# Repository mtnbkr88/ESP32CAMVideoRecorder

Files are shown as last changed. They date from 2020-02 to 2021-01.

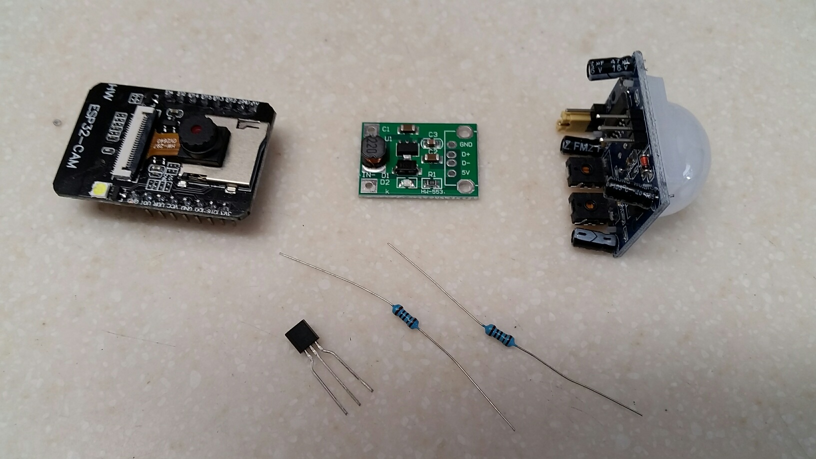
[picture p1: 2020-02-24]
ECVR_Parts.jpg

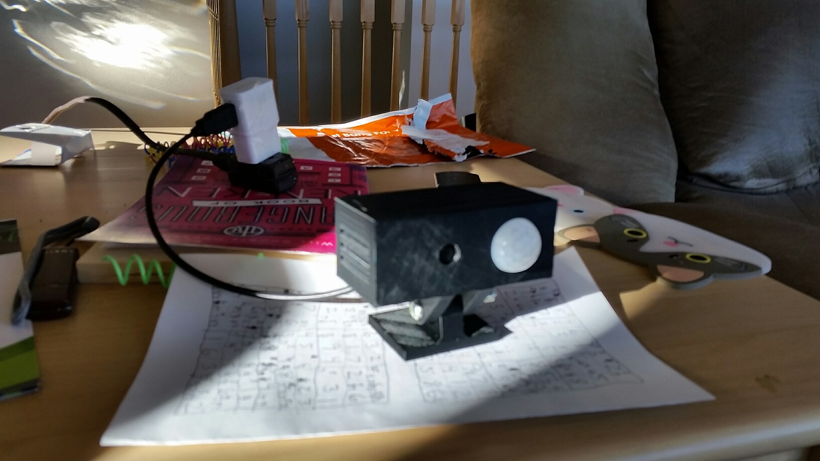
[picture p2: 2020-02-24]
ECVR_Enclosure.jpg

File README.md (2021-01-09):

# ESP32-CAM_Video_Recorder

ESP32-CAM Video Recorder

11/08/2020 Ed Williams 

This version of the ESP32-CAM Video Recorder is built on the work of many other listed in the sketch.
It has been hugely modified to be a fairly complete web camera server with the following capabilities:
  - Record AVI video and peak, stream, download or delete the saved videos.
  - Take JPG pictures and view, download or delete the saved pictures.
  - Up to 100 videos and 100 pictures can be saved on the SD card. Beyond that as more
    are saved the oldest are deleted.
  - Removed the ability to change the size, frame rate and quality. They are permanently 
    set to size 640x480, 100ms and quality 10.
  - Recording times can be set from 10 to 300 seconds
  - Motion detection is available if a PIR motion sensor is connected to GPIO3 (U0RXD)
    (after the firmware is uploaded). 
  - Time action trigger.
  - Remote trigger.
  - Motion detection and time can trigger the following actions:
    - Take a picture.
    - Take a picture and email it.
    - Make a video.
    - Make a video and send an email with name of video.   
  - Motion detection is checked every second and starts checking again one minute
    after a trigger, so if you don't want any gaps in motion detected videos, set 
    recording time to 60 seconds.
  - Normal web traffic is on port 80, streaming comes from port 90. If accessing from 
    outside the local network, forward port X to 80 and port X+10 to port 90.
  - OTA firmware updates on port 90.
  - The original included FTP server was removed since files can now be managed through
    the web site.
  - Note: This sketch uses a simple sendemail library I found on github by Peter Gorasz
    (sendemail.cpp and sendemail.h) but modified by me to allow sending one file from 
    the SD card as an attachment. The sendemail pieces are included in this sketch and 
    can be moved to external files if you want to use them for something else.
  - Use a top quality SD card with at least 16G. If the camera crashes after recording a
    lot of videos, the SD card might be full.

When using the camera and SD card, I was only able to get GPIO3 (U0RXD) pin to work
with the PIR but I had to wire it up as follows:

Use a 2N4401 transistor with the collector hooked to a 1K resistor then hooked to GPIO3
(connect after done uploading sketch). Connect the Dout wire from the PIR to a 1K resistor
then connect to base of transistor. Connect the emitter of the transistor to GND. See
ECVR_Schematic.jpg for a picture of the wiring.

Used pinMode(GPIO_NUM_3, INPUT_PULLUP) in the setup to pull the pin high. Now when 
motion is detected, GPIO3 will be pulled low, otherwise it will be high.

ECVR_Main_Screen.png shows the main screen for the ESP32-CAM Video Recorder web site.

ECVR_Parts.jpg shows the parts used.

The files ECVR_Box.stl, ECVR_Box_Cover.stl and ECVR_Box_Base.stl are stl files for
3D printing an enclosure to hold everything.

ECVR_Enclosure.jpg show the completed project.

If a motion detect or time trigger video is being recorded and send an email is enabled,
the email sometimes does not get sent. The socket for connecting to the email server fails.
I haven't figured this one out yet.

The Default Partition Scheme must be used for compiling so OTA can work.

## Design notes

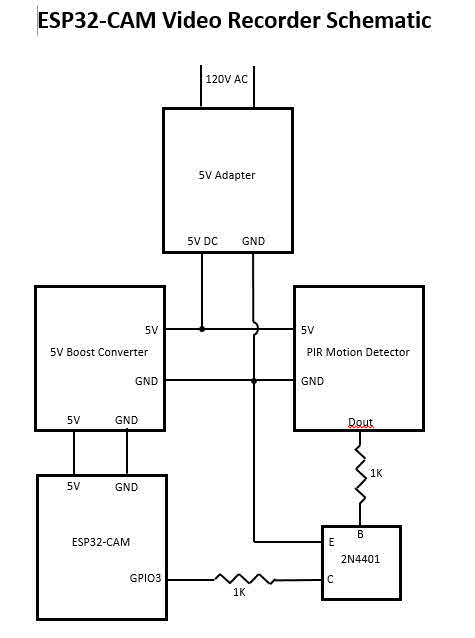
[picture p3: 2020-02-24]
ECVR_Schematic.jpg

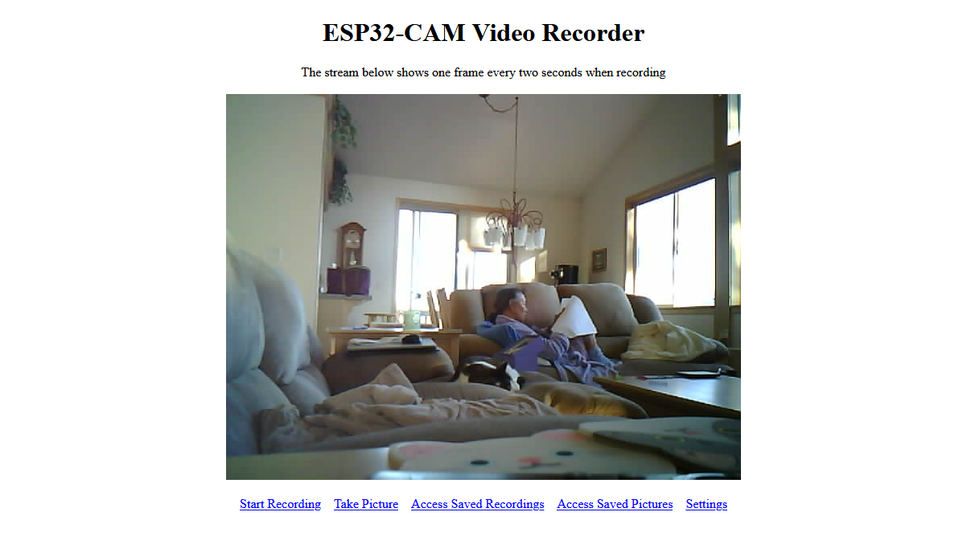
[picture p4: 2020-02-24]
ECVR_Main_Screen.png

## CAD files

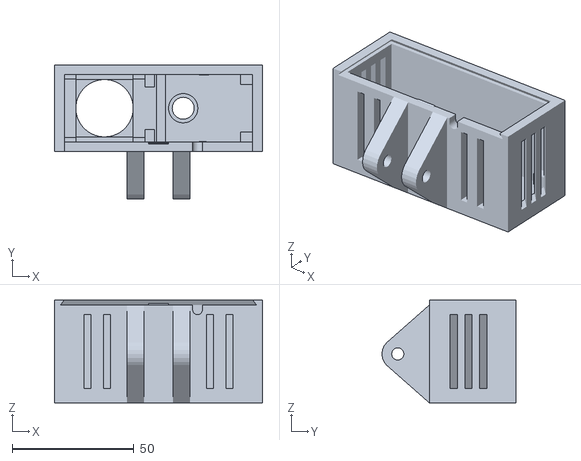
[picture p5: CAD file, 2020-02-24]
ECVR_Box.stl
85.2 x 55.0 x 42.2

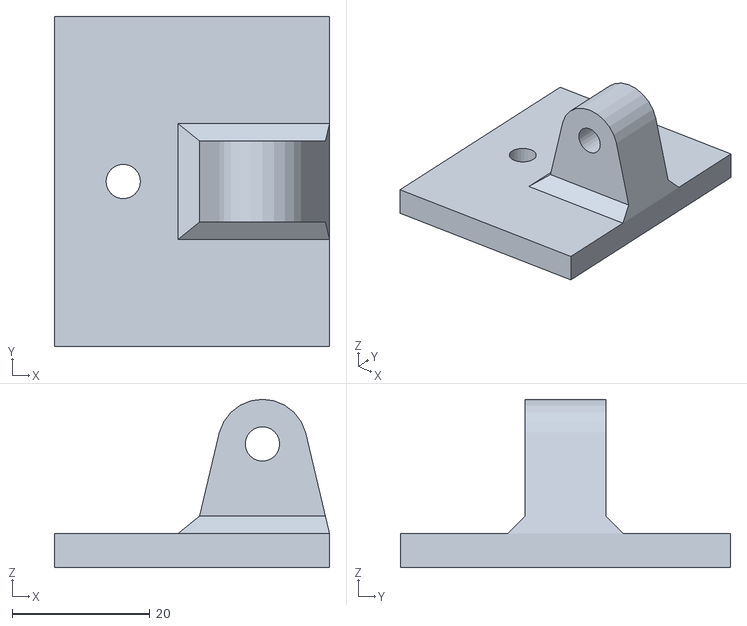
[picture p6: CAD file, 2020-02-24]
ECVR_Box_Base.stl
40.0 x 48.0 x 24.5

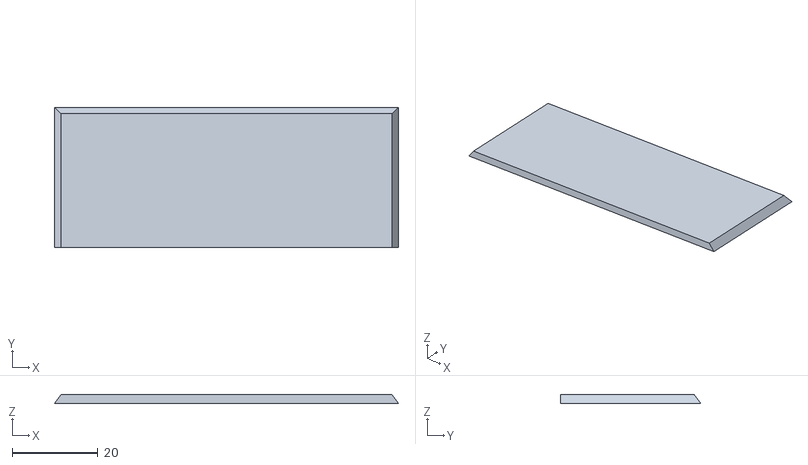
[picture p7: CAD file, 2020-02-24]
ECVR_Box_Cover.stl
80.2 x 32.8 x 2.00

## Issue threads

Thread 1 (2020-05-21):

Adding motion detection without PIR

thomas-pegot, 2020-05-21:
Hi,

>   - Motion detection is available if a PIR motion sensor is connected to GPIO3 (U0RXD)
>     (after the firmware is uploaded).

I you are interested in motion detection from video, I developped an algo based on optical flow which can be used to detect motion detection for esp32cam.

Link : https://github.com/thomas-pegot/esp32-motion

best,

mtnbkr88, 2020-05-21:
Hi,

Yes, I am interested in motion detection without using PIR. I thought about trying this myself many months ago but haven't gotten around to it yet. The PIR I'm using gives tons of false positives on hot or windy days (my cameras are outside). Detecting motion from video could solve the false positives from heat but I think there's nothing that can be done for windy days (lots of tree movement). When I get the chance I'll take a look at what you've done.

Thanks!

________________________________
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

thomas-pegot, 2020-05-30:
Ok take your time.
I added a repo presenting the motion library : https://github.com/thomas-pegot/camera_web_server
peace

Closed 2020-11-14.

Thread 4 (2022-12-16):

pir motion detection

yousefhstm, 2022-12-16:
hi mtnbkr88
1-great thank for you and your code skill
2-i upload the code and wire the circuit just like u say but madule donot take action ...even i measure the gpio 3 (it vas 0.6 volt )...how can i fix it? is it possible to change gpio 3 to low (input pulldown) and trigge it with pir(dout)?
3- some time my ESP32-CAM hangs(stick in reboot process) and the red led gose on continually (even after power off - on) until i program it with  standard EXAMPLE " CameraWebServer "that contain (define CAMERA_MODEL_AI_THINKER) then i can upload your code and get woke again ... it seem has issu with "ESP32 Wrover Module". how dose it fix?
thanks

mtnbkr88, 2022-12-16:
Hi yousefhstm,
1 - Thank you
2 - I use GPIO 13 and this code to initialize it: pinMode(GPIO_NUM_13, INPUT_PULLDOWN); so it gets triggered when PIT (DOUT) goes high.
3 - The red light is supposed to stay on during the setup phase and turn off once it goes into the loop phase. It is strange that it hangs in the setup phase for you. I use Arduino 1.8.15 and "ESP32 Wrover Module" as the board and in the code I used the pin definitions for CAMERA_MODEL_AI_THINKER. Have you tried connecting your module to your PC and using the Serial Monitor to hopefully see where it is hanging? You might have to add Serial.println statements in various places to hopefully catch where it is getting stuck. That's what I do for these situations.

Closed 2022-12-16.

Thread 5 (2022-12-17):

time trigger

yousefhstm, 2022-12-17:
hello dear mtnbkr88
 1_thanks for prev giude .it was help full and pir get work
2_ i wanna to take video or photo every 2min (for example) so i set "time trigger"at H=0 & M=2 but madule didnt take action...what can ido?
3_how can i turn the "SMD FLASH LAMP" off during madule work time?

mtnbkr88, 2022-12-18:
Hi Yousefhstm,
1 - Glad you got it working.
2 - Time Trigger is used to wake up the ESP32 at a specific time once a day for 10 minutes. This allows a person to remotely connect to the ESP32 to change settings or update firmware. My ESP32 is sitting on a fence in the yard with a solar panel attached. Using the time trigger mine wakes up once a day at 13:00 so I can make changes to settings without going outside.
3 - The SMD FLASH LAMP is connected to pin 4. You can try the following in your setup function to turn off the LED:
  pinMode(4, OUTPUT);     // flash led on chip
  digitalWrite(4, LOW);   // turn off the flash LED on chip
However pin 4 is also one of the pins used to access the SD card so the white LED will flash when the SD card is accessed. There's nothing that can be done about that. If you find a schematic of the ESP32CAM you will find this to be so. If the flash is really bothering you put a piece of black electrical tape over it.

yousefhstm, 2022-12-18:
Thanks

yousefhstm, 2022-12-18:
if this code have ota , how can i use it?

mtnbkr88, 2022-12-18:
Yes, this code has OTA. Here's how to use it:
1 - In the Arduino IDE choose Sketch->Export compiled binary. This will create the .bin file to upload.
2 - With the ESP32 being awake, go to http://<your_ip>/updatefirmware.
3 - Browse to and choose the .bin file saved above, enter the Update Password (the default is 12345678 if you did not change it) then choose Update.

yousefhstm, 2022-12-18:
Thank you

Closed 2022-12-18.

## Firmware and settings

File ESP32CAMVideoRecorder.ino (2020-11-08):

/********************************************************************************************

ESP32-CAM Video Recorder

11/08/2020 Ed Williams 

This version of the ESP32-CAM Video Recorder is built on the work of many other listed below.
It has been hugely modified to be a fairly complete web camera server with the following
capabilities:
  - Record AVI video and peak, stream, download or delete the saved videos.
  - Take JPG pictures and view, download or delete the saved pictures.
  - Save up to 100 videos and 100 pictures on the SD card. Beyond that as more are saved 
    the oldest are deleted.
  - Removed the ability to change the size, frame rate and quality. They are permanently 
    set to size 640x480, 100ms and quality 10.
  - Recording times can be set from 10 to 300 seconds
  - Motion detection is available if a PIR motion sensor is connected to GPIO3 (U0RXD)
    (after the firmware is uploaded). 
  - Time action trigger.
  - Remote trigger.
  - Motion detection and time can trigger the following actions:
    - Take a picture.
    - Take a picture and email it.
    - Make a video.
    - Make a video and send an email with name of video.
  - Motion detection is checked every second and starts checking again one minute
    after a trigger, so if you don't want any gaps in motion detected videos, set 
    recording time to 60 seconds.
  - Normal web traffic is on port 80, streaming comes from port 90. If accessing from 
    outside local network, forward port X to 80 and port X+10 to port 90.
  - OTA firmware updates on port 90.
  - The originally included FTP server was removed since files can now be managed through
    the web site.
  - Note: This sketch uses a simple sendemail library I found on github by Peter Gorasz
    (sendemail.cpp and sendemail.h) but modified by me to allow sending one file from 
    the SD card as an attachment. The sendemail pieces are included in this sketch and 
    can be moved to external files if you want to use them for something else.
  - Use a top quality SD card with at least 16G. If the camera crashes after recording a
    lot of videos, look on the Settings screeen to see if the SD card is full.

When using the camera and SD card, I was only able to get GPIO3 (U0RXD) pin to work
with the PIR but I had to wire it up as follows:

Use a 2N4401 transistor with the collector hooked to a 1K resistor then hooked to GPIO3
(connect after done uploading sketch). Connect the Dout wire from the PIR to a 1K resistor
then connect to base of transistor. Connect the emitter of the transistor to GND.

Used pinMode(GPIO_NUM_3, INPUT_PULLUP) in the setup to pull the pin high. Now when 
motion is detected, GPIO3 will be pulled low, otherwise it will be high.

For the remote trigger, connect to this server with a url like:
<this_server>/remotetrigger?action=10  (use 10 through 13 for the desired action)
  10 - Take a picture, 11 - Take a picture and email it, 12 - Take a video,
  13 - Take a video and email the video name

If a motion detect or time trigger video is being recorded and send an email is enabled,
the email sometimes does not get sent. The socket for connecting to the email server fails.
I haven't figured this one out yet.

The Default Partition Scheme must be used for compiling so OTA can work.


The descriptons below are from authors of previous versions of this sketch and some of 
the capabilities they describe, like using an FTP Server and changing size, frame rate 
and quality of recorded videos have been removed.

****************************************************************************************/

/* start of others old comments ********************************************************
***********************************************************************************************************************************************************
 *  TITLE: This sketch is derived from the following Github repository and is mainly for testing the current work done by the team. It allows you 
 *  to record video onto a microSD card, using the ESP32-CAM board. Videos can be remotely obtained by accessing the FTP server contained within the sketch.
 *
 *  By Frenoy Osburn
 *  YouTube Video: https://youtu.be/lc_gXfkoRZo
 *  BnBe Post: https://www.bitsnblobs.com/video-recording-with-the-esp32-cam-board
 ***********************************************************************************************************************************************************/
/********************************************************************************************************************
 *  Board Settings:
 *  Board: "ESP32 Wrover Module"
 *  Upload Speed: "921600"
 *  Flash Frequency: "80MHz"
 *  Flash Mode: "QIO"
 *  Partition Scheme: "Hue APP (3MB No OTA/1MB SPIFFS)"
 *  Core Debug Level: "None"
 *  COM Port: Depends *On Your System*
 *********************************************************************************************************************/
 
 /*
  TimeLapseAvi

  ESP32-CAM Video Recorder

  This program records an AVI video on the SD Card of an ESP32-CAM.

  by James Zahary July 20, 2019  TimeLapseAvi23x.ino
     jamzah.plc@gmail.com

  https://github.com/jameszah/ESP32-CAM-Video-Recorder
    jameszah/ESP32-CAM-Video-Recorder is licensed under the
    GNU General Public License v3.0

  ~~~
  Update Sep 15, 2019 TimeLapseAvi39x.ino
  - work-in-progress
  - I'm publishing this as a few people have been asking or working on this
  
  - program now uses both cpu's with cpu 0 taking pictures and queue'ing them
    and a separate task on cpu 1 moving the pictures from the queue and adding
    them to the avi file on the sd card
  - the loop() task on cpu 1 now just handles the ftp system and http server
  - dropped fixed ip and switch to mDNS with name "desklens", which can be typed into
    browser, and also used as wifi name on router
  - small change to ftp to cooperate with WinSCP program
  - fixed bug so Windows would calulcate the correct length (time length) of avi 
  - when queue of frames gets full, it slips every other frame to try to catch up
  - camera is re-configued when changing from UXGA <> VGA to allow for more buffers 
    with the smaller frames
  ~~~

  The is Arduino code, with standard setup for ESP32-CAM
    - Board ESP32 Wrover Module
    - Partition Scheme Huge APP (3MB No OTA)

  This program records an AVI video on the SD Card of an ESP32-CAM.

  It will record realtime video at limited framerates, or timelapses with the full resolution of the ESP32-CAM.
  It is controlled by a web page it serves to stop and start recordings with many parameters, and look through the viewfinder.

  You can control framesize (UXGA, VGA, ...), quality, length, and fps to record, and fps to playback later, etc.

  There is also an ftp server to download the recordings to a PC.

  Instructions:

  The program uses a fixed IP of 192.168.1.188, so you can browse to it from your phone or computer.

  http://192.168.1.188/ -- this gives you the status of the recording in progress and lets you look through the viewfinder

  http://192.168.1.188/stop -- this stops the recording in progress and displays some sample commands to start new recordings

  ftp://192.168.1.188/ -- gives you the ftp server

  The ftp for esp32 seems to not be a full ftp.  The Chrome Browser and the Windows command line ftp's did not work with this, but
  the Raspbarian command line ftp works fine, and an old Windows ftp I have called CoffeeCup Free FTP also works, which is what I have been using.
  You can download at about 450 KB/s -- which is better than having to retreive the SD chip if you camera is up in a tree!

  http://192.168.1.188/start?framesize=VGA&length=1800&interval=250&quality=10&repeat=100&speed=1&gray=0  -- this is a sample to start a new recording

  framesize can be UXGA, SVGA, VGA, CIF (default VGA)
  length is length in seconds of the recording 0..3600 (default 1800)
  interval is the milli-seconds between frames (default 200)
  quality is a number 5..50 for the jpeg  - smaller number is higher quality with bigger and more detailed jpeg (default 10)
  repeat is a number of how many of the same recordings should be made (default 100)
  speed is a factor to speed up realtime for a timelapse recording - 1 is realtime (default 1)
  gray is 1 for a grayscale video (default 0 - color)

  These factors have to be within the limit of the SD chip to receive the data.
  For example, using a LEXAR 300x 32GB microSDHC UHS-I, the following works for me:

  UXGA quality 10,  2 fps (or interval of 500ms)
  SVGA quality 10,  5 fps (200ms)
  VGA  quality 10, 10 fps (100ms)
  CIG  quality 10, 20 fps (50ms)

  If you increase fps, you might have to reduce quality or framesize to keep it from dropping frames as it writes all the data to the SD chip.

  Also, other SD chips will be faster or slower.  I was using a SanDisk 16GB microSDHC "Up to 653X" - which was slower and more unpredictable than the LEXAR ???

  Search for "zzz" to find places to modify the code for:
    1.  Your wifi name and password
    2.  Your preferred ip address (with default gateway, etc)
    3.  Your Timezone for use in filenames
    4.  Defaults for framesize, quality, ... and if the recording should start on reboot of the ESP32 without receiving a command

  Acknowlegements:

  1.  https://robotzero.one/time-lapse-esp32-cameras/
      Timelapse programs for ESP32-CAM version that sends snapshots of screen.
  2.  https://github.com/nailbuster/esp8266FTPServer
      ftp server (slightly modifed to get the directory function working)
  3.  https://github.com/ArduCAM/Arduino/tree/master/ArduCAM/examples/mini
      ArduCAM Mini demo (C)2017 LeeWeb: http://www.ArduCAM.com
      I copied the structure of the avi file, some calculations.

end of others old comments ***************************************************************
******************************************************************************************/


// edit the below for local settings 

// wifi info
const char* ssid = "YourSSID";
const char* password = "YourSSIDPwd";
// fixed IP info
const uint8_t IP_Address[4] = {192, 168, 2, 30};
const uint8_t IP_Gateway[4] = {192, 168, 2, 1};
const uint8_t IP_Subnet[4] = {255, 255, 255, 0};
const uint8_t IP_PrimaryDNS[4] = {8, 8, 8, 8};
const uint8_t IP_SecondaryDNS[4] = {8, 8, 4, 4};

const char* TZ_INFO = "PST8PDT,M3.2.0/2:00:00,M11.1.0/2:00:00";

const int SERVER_PORT = 80;  // port the the web server is listening on
            // the stream web server will be listening on this port + 10 

// edit email server info for the send part, recipient address is set through Settings in the app
const char* emailhost = "smtp.gmail.com";
const int emailport = 465;
const char* emailsendaddr = "YourEmail\@gmail.com";
const char* emailsendpwd = "YourEmailPwd";
char email[40] = "DefaultMotionDetectEmail\@hotmail.com";  // this can be changed through Settings in the app

// OTA update stuff
const char* appName = "ESP32CamVideoRecorder";
const char* appVersion = "1.4.3";
const char* firmwareUpdatePassword = "87654321";

// should not need to edit the below

#include <Update.h>  // for flashing new firmware

//#define LOG_LOCAL_LEVEL ESP_LOG_VERBOSE
#include "esp_log.h"
#include "esp_http_server.h"
#include "esp_camera.h"

//#include <WiFi.h>   // redundant

//#include "SD_MMC.h"  // redundant
//#include <FS.h>      // redundant


/**********************************************************************************
 * 
 *  From here to end comment below is the contents of sendemail.h
 *
 *  If an SD card is used, it is assumed to be mounted on /sdcard.
 * 
 */

#ifndef __SENDEMAIL_H
#define __SENDEMAIL_H

// uncomment for debug output on Serial port
//#define DEBUG_EMAIL_PORT

// uncomment if using SD card
#define USING_SD_CARD

#include <WiFiClient.h>
#include <WiFiClientSecure.h>
#include <base64.h>

#ifdef USING_SD_CARD
#include <FS.h>
#include "SD_MMC.h"
#endif


class SendEmail
{
  private:
    const String host;
    const int port;
    const String user;
    const String passwd;
    const int timeout;
    const bool ssl;
    WiFiClient* client;
    String readClient();

    // stuff for attaching buffers (could be images and videos held in memory)
    int attachbuffercount;  // current number of buffer attachments
    static const int attachbuffermaxcount = 10;  // max number of buffers that can be attached
    struct attachbufferitem {
      char * buffername;  // name for buffer
      char * buffer;  // pointer to buffer
      size_t buffersize;  // number of bytes in buffer
    };
    attachbufferitem attachbufferitems[attachbuffermaxcount];
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
void loop()
{
/*
  if (WiFi.status() != WL_CONNECTED) {
    init_wifi();
    Serial.println("***** WiFi reconnect *****");
  }
*/
  if (millis() - last_wakeup_1sec > (1000) ) {       // 1 second
    last_wakeup_1sec = millis();

    if (WiFi.status() != WL_CONNECTED) {
      init_wifi();
      Serial.println("***** WiFi reconnect *****");
    }

    if ( motionDetect > 9 && motion == 0 && !digitalRead( PIR_Pin ) ) { // Low if motion detected
      int mcount = 0;
      while ( !digitalRead ( PIR_Pin ) && mcount < 4 ) {
        delay(5);
        mcount++;
        if ( mcount == 4 ) {
          // function to handle motion detected
          motion = 1;
          motion1min = millis();
          process_Detection(0);  // 0 is motion detection 
        }
      }
      
    }
  }

  if ( millis() - last_wakeup_1min > (1 * 60 * 1000) ) {       // 1 minute
    last_wakeup_1min = millis();

    // check current time and restart web servers after midnight (in case it got stuck during the day)
    struct tm timeinfo;
    if (!getLocalTime(&timeinfo)) {
      Serial.println("Failed to obtain time");
    } else {
      char hc[3];  // current hour
      strftime(hc, sizeof(hc), "%H", &timeinfo);
      int h = atoi(hc);
      char mc[3];  // current minute
      strftime(mc, sizeof(mc), "%M", &timeinfo);
      int m = atoi(mc);

      // restart stream web server at midnight just in case it is stuck
      if ( h == 0 && m == 0 ) {
        Serial.println("Daily restart of StreamServer");
        stopStreamServer();
        delay(500);
        startStreamServer();
      }

      // check if time trigger happened
      if ( triggerDetect > 9 && triggerH == h && triggerM == m ) {
        // do time trigger
        process_Detection(1);  // 1 is time trigger detection 
      }
    }
  }

  if ( millis() - motion1min > (1 * 60 * 1000) && motion == 1 ) {  // 1 motion minute
    // allow motion detection after 1 minute
    motion = 0;
  }
 
  if (millis() - last_wakeup_10min > (10 * 60 * 1000) ) {       // 10 minutes
    last_wakeup_10min = millis();
    print_stats("Wakeup in loop() Core: ");
/*
    // restart the main camera web server - it easily gets stuck
    Serial.println("Restarting CameraServer in case it got stuck");
    stopCameraServer();
    delay(500);
    startCameraServer();
*/    
  }

  delay(200);

}


/*****************************************************************************
 * 
 *  From here to the end is the contents of sendemail.cpp
 *  This version can send text or binary objects (jpg, avi) from memory as attachments
 *  and can send files from the SD card mounted on /sdcard.
 *  
 *  *** Uncomment the #include if the below is moved back into sendemail.cpp ***
 *
 */

//#include "sendemail.h"

SendEmail::SendEmail(const String& host, const int port, const String& user, const String& passwd, const int timeout, const bool ssl) :
    host(host), port(port), user(user), passwd(passwd), timeout(timeout), ssl(ssl), client((ssl) ? new WiFiClientSecure() : new WiFiClient())
{
  attachbuffercount = 0;
#ifdef USING_SD_CARD
  attachfilecount = 0;
#endif
}

String SendEmail::readClient()
{
  String r = client->readStringUntil('\n');
  r.trim();
  while (client->available()) r += client->readString();
  return r;
}

void SendEmail::attachbuffer(char * name, char * bufptr, size_t bufsize)
{
  attachbufferitems[attachbuffercount].buffername = (char *) malloc( strlen(name)+1 );
  strcpy( attachbufferitems[attachbuffercount].buffername, name ); 
  attachbufferitems[attachbuffercount].buffer = bufptr;
  attachbufferitems[attachbuffercount].buffersize = bufsize;
  
  attachbuffercount++;
}

#ifdef USING_SD_CARD
void SendEmail::attachfile(char * name)
{
  attachfileitems[attachfilecount].filename = (char *) malloc( strlen(name)+8 );
  strcpy( attachfileitems[attachfilecount].filename, "/sdcard" );
  strcat( attachfileitems[attachfilecount].filename, name );
  
  attachfilecount++;
}
#endif


bool SendEmail::send(const String& from, const String& to, const String& subject, const String& msg)
{
  if (!host.length())
  {
    return false;
  }
  String buffer2((char *)0);  // create String without memory allocation
  buffer2.reserve(800);  // now allocate bytes for string, really should only use 780 of it
  client->stop();
  client->setTimeout(timeout);
  // smtp connect
#ifdef DEBUG_EMAIL_PORT
  Serial.print(F("Connecting: "));
  Serial.print(host);
  Serial.print(":");
  Serial.println(port);
#endif
  if (!client->connect(host.c_str(), port))
  {
    return false;
  }
  String buffer = readClient();
#ifdef DEBUG_EMAIL_PORT
  Serial.print(F("SERVER->CLIENT: "));
  Serial.println(buffer);
#endif
  // note: F(..) as used below puts the string in flash instead of RAM
  if (!buffer.startsWith(F("220")))
  {
    return false;
  }
  buffer = F("HELO ");
  buffer += client->localIP();
  client->println(buffer);
#ifdef DEBUG_EMAIL_PORT
  Serial.print(F("CLIENT->SERVER: "));
  Serial.println(buffer);
#endif
  buffer = readClient();
#ifdef DEBUG_EMAIL_PORT
  Serial.print(F("SERVER->CLIENT: "));
  Serial.println(buffer);
#endif
  if (!buffer.startsWith(F("250")))
  {
    return false;
  }
  if (user.length()>0  && passwd.length()>0 )
  {
    buffer = F("AUTH LOGIN");
    client->println(buffer);
#ifdef DEBUG_EMAIL_PORT
  Serial.print(F("CLIENT->SERVER: "));
  Serial.println(buffer);
#endif
    buffer = readClient();
#ifdef DEBUG_EMAIL_PORT
  Serial.print(F("SERVER->CLIENT: "));
  Serial.println(buffer);
#endif
    if (!buffer.startsWith(F("334")))
    {
      return false;
    }
    base64 b;
    buffer = user;
    buffer = b.encode(buffer);
    client->println(buffer);
#ifdef DEBUG_EMAIL_PORT
  Serial.print(F("CLIENT->SERVER: "));
  Serial.println(buffer);
#endif
    buffer = readClient();
#ifdef DEBUG_EMAIL_PORT
  Serial.print(F("SERVER->CLIENT: "));
  Serial.println(buffer);
#endif
    if (!buffer.startsWith(F("334")))
    {
      return false;
    }
    buffer = this->passwd;
    buffer = b.encode(buffer);
    client->println(buffer);
#ifdef DEBUG_EMAIL_PORT
  Serial.print(F("CLIENT->SERVER: "));
  Serial.println(buffer);
#endif
    buffer = readClient();
#ifdef DEBUG_EMAIL_PORT
  Serial.print(F("SERVER->CLIENT: "));
  Serial.println(buffer);
#endif
    if (!buffer.startsWith(F("235")))
    {
      return false;
    }
  }
  // smtp send mail
  buffer = F("MAIL FROM: ");
  buffer += from;
  client->println(buffer);
#ifdef DEBUG_EMAIL_PORT
  Serial.print(F("CLIENT->SERVER: "));
  Serial.println(buffer);
#endif
  buffer = readClient();
#ifdef DEBUG_EMAIL_PORT
  Serial.print(F("SERVER->CLIENT: "));
  Serial.println(buffer);
#endif
  if (!buffer.startsWith(F("250")))
  {
    return false;
  }
  buffer = F("RCPT TO: ");
  buffer += to;
  client->println(buffer);
#ifdef DEBUG_EMAIL_PORT
  Serial.print(F("CLIENT->SERVER: "));
  Serial.println(buffer);
#endif
  buffer = readClient();
#ifdef DEBUG_EMAIL_PORT
  Serial.print(F("SERVER->CLIENT: "));
  Serial.println(buffer);
#endif
  if (!buffer.startsWith(F("250")))
  {
    return false;
  }
  buffer = F("DATA");
  client->println(buffer);
#ifdef DEBUG_EMAIL_PORT
  Serial.print(F("CLIENT->SERVER: "));
  Serial.println(buffer);
#endif
  buffer = readClient();
#ifdef DEBUG_EMAIL_PORT
  Serial.print(F("SERVER->CLIENT: "));
  Serial.println(buffer);
#endif
  if (!buffer.startsWith(F("354")))
  {
    return false;
  }
  buffer = F("From: ");
  buffer += from;
  client->println(buffer);
#ifdef DEBUG_EMAIL_PORT
  Serial.print(F("CLIENT->SERVER: "));
  Serial.println(buffer);
#endif
  buffer = F("To: ");
  buffer += to;
  client->println(buffer);
#ifdef DEBUG_EMAIL_PORT
  Serial.print(F("CLIENT->SERVER: "));
  Serial.println(buffer);
#endif
  buffer = F("Subject: ");
  buffer += subject;
  client->println(buffer);
#ifdef DEBUG_EMAIL_PORT
  Serial.print(F("CLIENT->SERVER: "));
  Serial.println(buffer);
#endif
  // setup to send message body
  buffer = F("MIME-Version: 1.0\r\n");
  buffer += F("Content-Type: multipart/mixed; boundary=\"{BOUNDARY}\"\r\n\r\n");
  buffer += F("--{BOUNDARY}\r\n");
  buffer += F("Content-Type: text/plain\r\n");
  client->println(buffer);
#ifdef DEBUG_EMAIL_PORT
  Serial.print(F("CLIENT->SERVER: "));
  Serial.println(buffer);
#endif
  buffer = msg;
  client->println(buffer);
#ifdef DEBUG_EMAIL_PORT
  Serial.print(F("CLIENT->SERVER: "));
  Serial.println(buffer);
#endif
  // process buffer attachments
  for ( int i = 0; i < attachbuffercount; i++ ) {
    char * pos = attachbufferitems[i].buffer;
    size_t alen = attachbufferitems[i].buffersize;
    base64 b;
    
    buffer = F("\r\n--{BOUNDARY}\r\n");
    buffer += F("Content-Type: application/octet-stream\r\n");
    buffer += F("Content-Transfer-Encoding: base64\r\n");
    buffer += F("Content-Disposition: attachment;filename=\"");
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

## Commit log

2020-05-23 Update ESP32CAMVideoRecorder.ino
    Version 1.3.4 has significant performance and reliability improvements.
2020-07-05 Update ESP32CAMVideoRecorder.ino
    This update includes a fix for the often seen Camera init failed with error 0x20004
    [ESP32CAMVideoRecorder.ino]
2020-11-08 Update ESP32CAMVideoRecorder.ino
    Changed FPS from 8 to 10.
